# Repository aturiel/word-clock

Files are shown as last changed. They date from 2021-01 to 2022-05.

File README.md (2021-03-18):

# Spanish WordClock

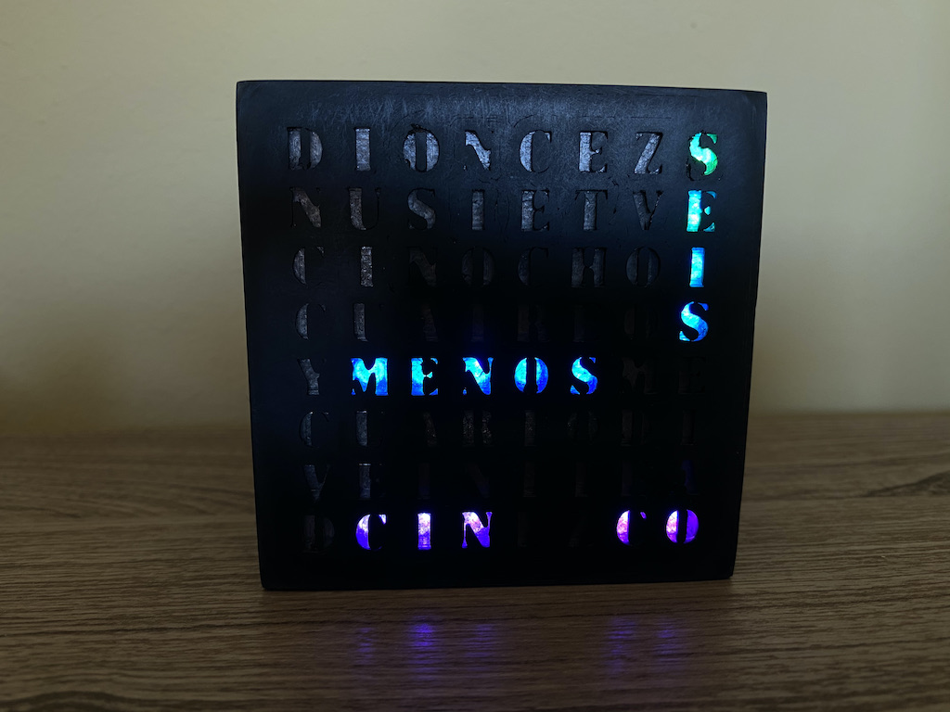
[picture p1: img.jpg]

https://www.thingiverse.com/thing:4746782

## Features include:
* Accurate Clock refresh off Internet Time Servers
* Configured through Web Interface
* Display WordClock status on web server
* Basic Authorization around Configuration web interface
* Support for OTA (loading firmware over WiFi)
* Update firmware through web interface
* Configurable leds off/off times
* Configurable rainbow animation on the hour
* Based on:
  * Marquee Scroller by Qrome - https://github.com/Qrome/marquee-scroller 
  * 3D Printable NeoMatrix 8x8 Word by PawArmy - https://www.thingiverse.com/thing:931777

## Required Parts:
* Node MCU ESP8266
* CJMCU 64 Bit WS2812 5050 RGB NeoPixel MAtrix 8x8: https://www.banggood.com/CJMCU-64-Bit-WS2812-5050-RGB-LED-Driver-Development-Board-p-981678.html
* AC-DC 5V

Note: Using the links provided here help to support these types of projects. Thank you for the support.  

## Wiring 
* Please check https://github.com/Aircoookie/WLED/wiki 
* BUZZER_PIN *  D5
* LED_PIN     D4

## 3D Printed Case
Modified to match my 8x8 LED matrix from a design by [PawArmy](https://www.thingiverse.com/thing:931777)

## Compiling and Loading to ESP8266
It is recommended to use Arduino IDE.  You will need to configure Arduino IDE to work with your board and USB port and installed the required USB drivers etc.  
* Plase check [Marquee Scroller by Qrome](https://github.com/Qrome/marquee-scroller) project

## Loading Supporting Library Files in Arduino
Use the Arduino guide for details on how to installing and manage libraries https://www.arduino.cc/en/Guide/Libraries  
**Packages** -- the following packages and libraries are used (download and install):  

"FS.h"
<ESP8266WiFi.h>
<ESP8266WebServer.h>
<ESP8266HTTPUpdateServer.h>
<WiFiManager.h> // --> https://github.com/tzapu/WiFiManager
<ArduinoOTA.h>
<NTPClient.h> // --> https://github.com/arduino-libraries/NTPClient
<Adafruit_NeoPixel.h> // --> https://github.com/adafruit/Adafruit_NeoPixel

## Web Interface
The WordClock uses the **WiFiManager** so when it can't find the last network it was connected to 
it will become a **AP Hotspot** -- connect to it **WORD-CLOCK-chipID.local** with your phone and you can then enter your WiFi connection information.

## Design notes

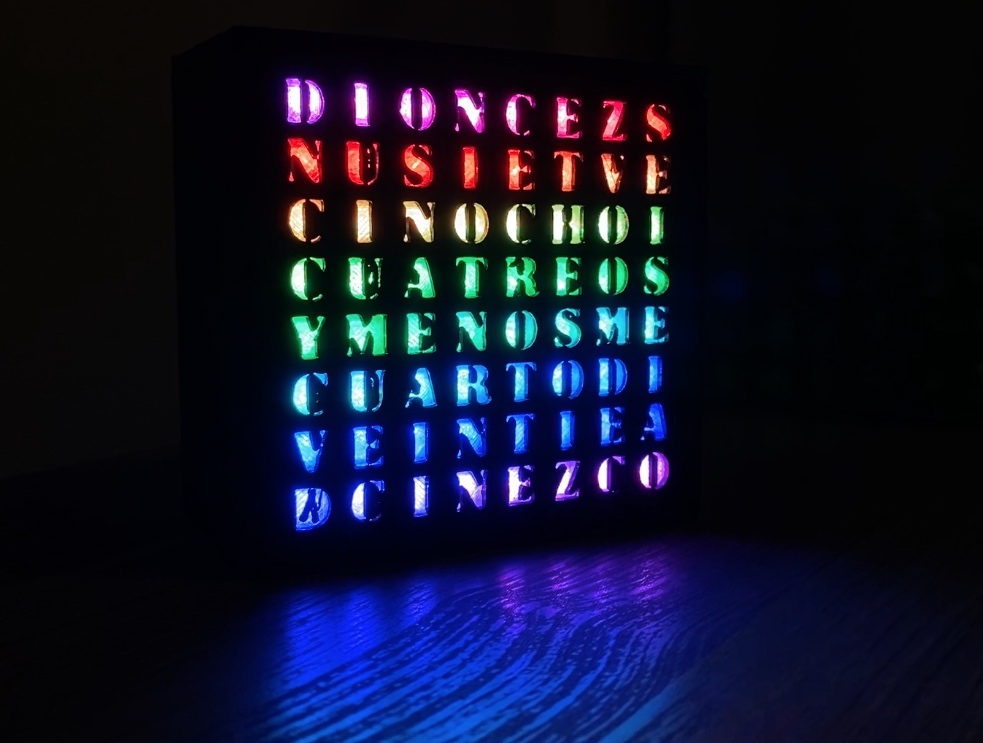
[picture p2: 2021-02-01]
STL/images/face.jpg

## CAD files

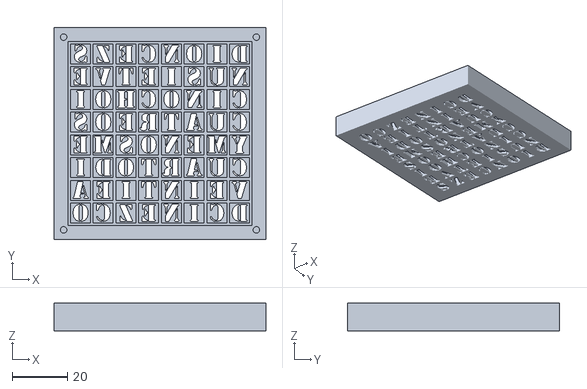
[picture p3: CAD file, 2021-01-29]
STL/3D_Printable_NeoMatrix_8x8_Word_Clock/files/Alberto - WordClock-face_spanish.stl
77.0 x 77.0 x 10.0

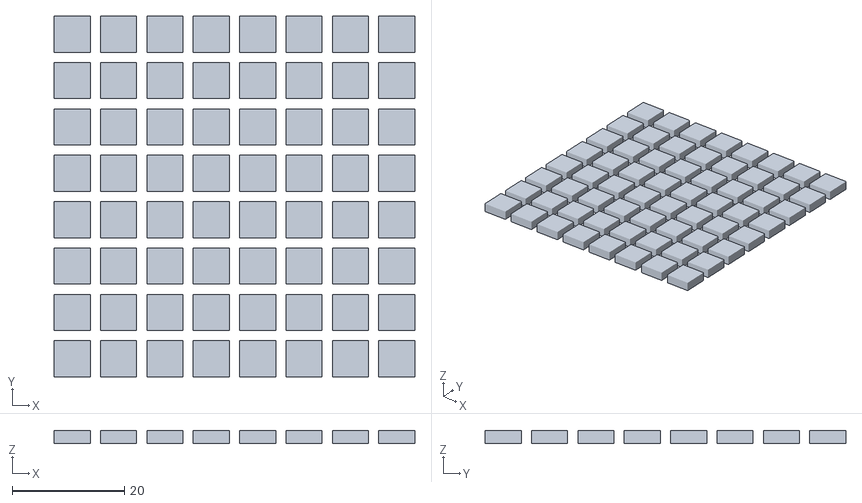
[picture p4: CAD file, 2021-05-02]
STL/WordClock-diffusers-2.stl
64.2 x 64.2 x 2.25

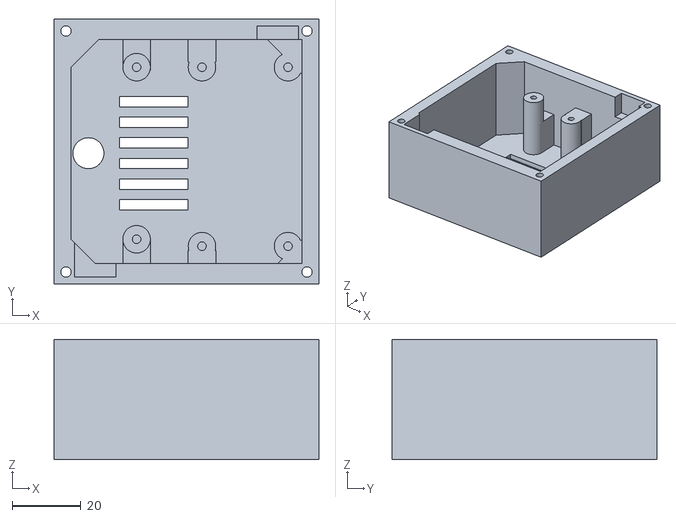
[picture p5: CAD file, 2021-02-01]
STL/WordClock-back.stl
77.0 x 77.0 x 35.0

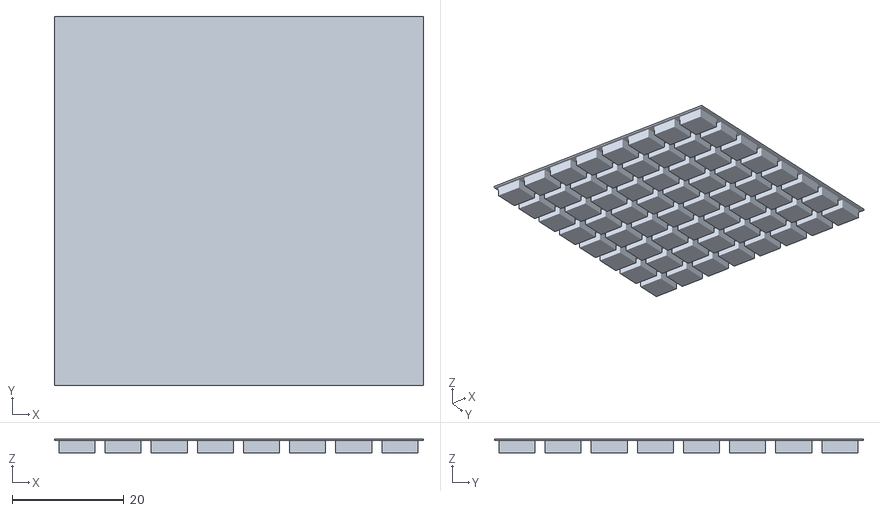
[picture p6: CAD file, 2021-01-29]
STL/WordClock-diffusers.stl
66.0 x 66.0 x 2.55

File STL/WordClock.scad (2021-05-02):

letters = [ 
    ["D", "I", "O", "N", "C", "E", "Z", "S"],
    ["N", "U", "S", "I", "E", "T", "V", "E"],
    ["C", "I", "N", "O", "C", "H", "O", "I"],
    ["C", "U", "A", "T", "R", "E", "O", "S"],
    ["Y", "M", "E", "N", "O", "S", "M", "E"],
    ["C", "U", "A", "R", "T", "O", "D", "I"],
    ["V", "E", "I", "N", "T", "I", "E", "A"],
    ["D", "C", "I", "N", "E", "Z", "C", "O"],    
];

$fn = 64;
max = 66;   // led side?
s = 66/8;
d_h = 5;    // led dividers?
w_h = 10;   // face height
b_h = 5;    // dividers height
c_h = 35;   // base height
letter_depth = w_h+1;

diffusers_height = 2.25;

font_face = "stencil std";
font_brand = "futura";

module face()
{
	for (r = [0:7])
	{
		for (c = [0:7])
		{
			#translate([r*s + s/2+.4, c*s+s/2+.5, 0])
				linear_extrude(height = letter_depth+1)
					text(
						letters[7-c][r], 
						font = font_face,
						size=6, 
						$fn=20, 
						valign="center", 
						halign = "center"
					);
		}
	}
}

module case_front()
{
	difference()
	{
		union()
		{
			translate([-5,-5,0]) 	cube([5,max+6+5, w_h]);	// left side
			translate([max+1,-5,0])	cube([5,max+6+5, w_h]); // right side 
			translate([0,max+1,0]) 	cube([max+2, 5, w_h]);	// top
			translate([-1,-5,0])	cube([max+3, 5, w_h]); 	// bottom
		}
		
		// mounting holes
		
		translate([-1.5,-1.5,0]) 			cylinder(d=2.4,h=w_h-2);	// ll 
		translate([max+1+1.5,-5+3.5,0]) 	cylinder(d=2.4,h=w_h-2);	// lr
		translate([-1.5,max+1+1.5,0]) 		cylinder(d=2.4,h=w_h-2);	// ul
		translate([max+1+1.5,max+1+1.5,0])	cylinder(d=2.4,h=w_h-2);	// ur 
	}
}

module dividers(w=1)
{
	for (x = [0:8])
	{
		translate([s*x, 1, 0]) cube([w,max,d_h]);
		translate([0, s*x,0]) cube([max+1, w, d_h]);
	}
}

module clock_face()
{
	difference()
	{
		union()
		{
			translate([0,0,w_h-1]) cube([max+1,max+1,1]);
			translate([0,0,b_h]) dividers();
		}
		face();
	}
	case_front();
}

module diffusers()
{
	difference()
	{
		translate([1,1,0]) cube([max,max,diffusers_height]);
		dividers(1.8);
	}	
    //translate([1,1,diffusers_height]) cube([max,max,0.30]);
}

module standoff( height, width_bottom, width_top)
{
	difference()
	{
		cylinder(d1=width_bottom,d2=width_top,h=height);
		translate([0,0,height-10+1])	cylinder(d=2.5, h=10);
	}
}

module case_back()
{
	difference()
	{
		union()
		{
			cube([max+1, max+1, 2]);
			translate([   -5,  -5, 0]) 		cube([5    , max+6+5, c_h]);	// left side
			translate([max+1,  -5, 0])		cube([5    , max+6+5, c_h]);    // right side 
			translate([    0, max, 0]) 	    cube([max+2,       6, c_h]);	// top
			translate([   -1,  -5, 0])		cube([max+2,       6, c_h]); 	// bottom
            
            // reinforcement bottom left
            translate([ -1, -1, 0])      
                linear_extrude(height = c_h, convexity = 10, twist = 0)
                polygon(points=[[0,0],[10,0],[0,10]], paths=[[0,1,2]]);

            // reinforcement bottom right
            #translate([ -1, max+1, 0])      
                linear_extrude(height = c_h, convexity = 10, twist = 0)
                polygon(points=[[0,0],[10,0],[0,-10]], paths=[[0,1,2]]);
            
            // reinforcement top left
            translate([ max+1, -1, 0])      
                linear_extrude(height = esp_height+2, convexity = 10, twist = 0)
                polygon(points=[[0,0],[-9,0],[0,9]], paths=[[0,1,2]]);
            
            // reinforcement top right
            translate([ max+1, max+1, 0])      
                linear_extrude(height = esp_height+2, convexity = 10, twist = 0)
                polygon(points=[[0,0],[-11,0],[0,-11]], paths=[[0,1,2]]);
		}
		
		// mount holes 
        screwDeep = 17;
		translate([     -1.5,      -1.5, 0]) 	cylinder(d=3,h=c_h+1);	// ll 
		translate([max+1+1.5,    -5+3.5, 0]) 	cylinder(d=3,h=c_h+1);	// lr
		translate([     -1.5, max+1+1.5, 0]) 	cylinder(d=3,h=c_h+1);	// ul
		translate([max+1+1.5, max+1+1.5, 0])	cylinder(d=3,h=c_h+1);	// ur 
		
		translate([     -1.5,      -1.5, 0]) 	cylinder(d=5.5,h=c_h-screwDeep);	// ll 
		translate([max+1+1.5,    -5+3.5, 0]) 	cylinder(d=5.5,h=c_h-screwDeep);	// lr
		translate([     -1.5, max+1+1.5, 0]) 	cylinder(d=5.5,h=c_h-screwDeep);	// ul
		translate([max+1+1.5, max+1+1.5, 0])	cylinder(d=5.5,h=c_h-screwDeep);	// ur 
        
        // ventilation grill
        tol = 0.2;
        translate([14,16.5,0])	
             difference(){
               linear_extrude(height = 10)
               cube([16,30,10]);
               for (y=[0:6:30]){
                   translate([0,y,0]){
                     cube([20,3,5]);
                   }
               }
             }
        
        // slots for LED connector
        led_connector_deep = 9;
		#translate([max-12, max-0.5, c_h-led_connector_deep])	cube([12, 4.5, led_connector_deep]); 	
		#translate([     1,      -3, c_h-led_connector_deep])	cube([12, 10, led_connector_deep]);
            
		// power socket cutout
		translate([5,(max/2),0])
			 cylinder(d=9,h=6, center=true);
		
        // brand
        /*
		translate([max/2+15,max/2,0.3]) rotate([180,0,90])
					linear_extrude(height = 0.3)
					text(
						"Word-Clock", 
						font = font_brand,
						size=6, 
						$fn=20, 
						valign="center", 
						halign = "center"
					);
        */
	}
    
    // debug modules
    //#translate([6, 13, 3])	cube([28, 40, 23]); 	// AC-DC
    //#translate([35, 3, 5])	cube([31, 60, 18]); 	// ESP
    
    // strandoffs
    width_bottom = 8;
    width_top = 8;
    
	// standoffs for AC-DC
    acdc_height = 24;
    acdc_length = 50;
    acdc_x = 5+5+9;
    acdc_y = 8;
	translate([acdc_x, acdc_y             , 2]) standoff(acdc_height, width_bottom, width_top);
	translate([acdc_x, acdc_y+acdc_length , 2]) standoff(acdc_height, width_bottom, width_top);
    
	// standoffs for ESP 
    esp_height = 21;
    esp_width = 25;
    esp_length = 52;
    esp_x = 5+5+28;
    esp_y = 6;
	translate([esp_x          , esp_y             , 2]) standoff(esp_height, width_bottom, width_top);
	translate([esp_x+esp_width, esp_y             , 2]) standoff(esp_height, width_bottom, width_top);
	translate([esp_x          , esp_y+esp_length  , 2]) standoff(esp_height, width_bottom, width_top);
	translate([esp_x+esp_width, esp_y+esp_length  , 2]) standoff(esp_height, width_bottom, width_top);
    
    // aditional supports for AC-DC
	#translate([acdc_x-(width_top/2), 0    , 2])    cube([8,8,14]);
	#translate([acdc_x-(width_top/2), max-9, 2]) 	cube([8,9,14]);

    // aditional supports for ESP 
	#translate([esp_x-(width_top/2),     0, 2])     cube([8,4.7,esp_height]);
	#translate([esp_x-(width_top/2), max-6.5, 2])   cube([8,7,esp_height]); 
}

// uncomment for clock face
//translate([-15,0,10]) rotate([0,180,0]) clock_face();

// uncomment for led diffusers
translate([0,-80,0]) diffusers();

// uncomment for back of case
//case_back();

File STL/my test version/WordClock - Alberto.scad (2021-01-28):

letters = [
    ["C", "U", "A", "T", "R", "E", "O", "S"],
    ["N", "U", "S", "I", "E", "T", "V", "E"],
    ["C", "I", "N", "O", "C", "H", "O", "I"],
    ["D", "I", "O", "N", "C", "E", "Z", "S"],
    ["Y", "M", "E", "N", "O", "S", "M", "E"],
    ["C", "U", "A", "R", "T", "O", "D", "I"],
    ["V", "E", "I", "N", "T", "I", "E", "A"],
    ["D", "C", "I", "N", "E", "Z", "C", "O"],
];
cells = 8;

$fn=100;

font_name = "stencil std";
font_size = 6.5;

panel_extrude = 2;
letters_extrude = 1;

led_space = 3.26;
led_side = 5;

// grid
show_grid = true;
grid_width = 1.3;
grid_height = 5;

letter_size = led_space + led_side;
total_side = letter_size * cells;
init_column = (letter_size/2);
init_row = total_side - (letter_size/2);

difference() {
    cube (size=[total_side, total_side, panel_extrude]);

    x = 0;
    y = 0; 
    for( row = [0:cells-1]) {
        for( column = [0:cells-1]) {
            translate([0,0,panel_extrude-letters_extrude])
            linear_extrude(height=letters_extrude+1)
                translate([
                    init_column + (column*letter_size), 
                    init_row - (row*letter_size)
                ])
                text(letters[row][column],
                    font=font_name, size=font_size, 
                    halign="center", valign="center");
            
            x = x + led_side + led_space;
        }
        y = y + led_side + led_space;
    }
}


if(show_grid) {
    
    for (i = [0:cells]) {
        color("red", alpha=0.5)
        translate ([0, i*letter_size, grid_height])
        cube (size=[total_side, led_space, grid_width]);
        
        color("red", alpha=0.5)
        translate ([i*letter_size, 0, grid_height])
        cube (size=[led_space, total_side, grid_width]);
    }
}

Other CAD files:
STL/WordClock-face_spanish.stl

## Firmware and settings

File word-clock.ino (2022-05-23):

/** The MIT License (MIT)

  Copyright (c) 2018 David Payne

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
  THE SOFTWARE IS PROVIDED "AS IS", WITHOUT WARRANTY OF ANY KIND, EXPRESS OR
  IMPLIED, INCLUDING BUT NOT LIMITED TO THE WARRANTIES OF MERCHANTABILITY,
  FITNESS FOR A PARTICULAR PURPOSE AND NONINFRINGEMENT. IN NO EVENT SHALL THE
  AUTHORS OR COPYRIGHT HOLDERS BE LIABLE FOR ANY CLAIM, DAMAGES OR OTHER
  LIABILITY, WHETHER IN AN ACTION OF CONTRACT, TORT OR OTHERWISE, ARISING FROM,
  OUT OF OR IN CONNECTION WITH THE SOFTWARE OR THE USE OR OTHER DEALINGS IN THE
  SOFTWARE.
*/

/**********************************************
  Edit Settings.h for personalization
***********************************************/

#include "Settings.h"
#define VERSION "1.0"

#define HOSTNAME "WORD-CLOCK-"
#define CONFIG "/conf.txt"

//declairing prototypes
void configModeCallback (WiFiManager *myWiFiManager);
int8_t getWifiQuality();

// Define NTP Client to get time
// automatic summer time => https://github.com/RoboUlbricht/arduinoslovakia/blob/master/esp8266/ntp_client/ntp_client.ino
WiFiUDP ntpUDP;
// now we have a setting in the config
//long utcOffsetInSeconds = 3600 * 2;
//NTPClient timeClient(ntpUDP, "pool.ntp.org", utcOffsetInSeconds);
NTPClient timeClient(ntpUDP, "pool.ntp.org");

// HTML to simulate word-clock
String wordClockSimulated = "";

//
int displayedMinutes = 0;
boolean displayOn = true;

ESP8266WebServer server(WEBSERVER_PORT);
ESP8266HTTPUpdateServer serverUpdater;

static const char WEB_ACTIONS1[] PROGMEM = "<a class='w3-bar-item w3-button' href='/'><i class='fas fa-home'></i> Home</a>"
    "<a class='w3-bar-item w3-button' href='/configure'><i class='fas fa-cog'></i> Configure</a>"
    "<a class='w3-bar-item w3-button' href='/display'>";

static const char WEB_ACTION2[] PROGMEM = "</a><a class='w3-bar-item w3-button' href='#' onClick='confirm(\"Are you sure your want to reboot?\") && window.location.replace(\"/reboot\");'><i class='fas fa-power-off'></i> Reboot</a>"
    "<a class='w3-bar-item w3-button' href='/systemreset' onclick='return confirm(\"Do you want to reset to default settings?\")'><i class='fas fa-undo'></i> Reset Settings</a>"
    "<a class='w3-bar-item w3-button' href='/forgetwifi' onclick='return confirm(\"Do you want to forget to WiFi connection?\")'><i class='fas fa-wifi'></i> Forget WiFi</a>"
    "<a class='w3-bar-item w3-button' href='/update'><i class='fas fa-wrench'></i> Firmware Update</a>";
//                     "<a class='w3-bar-item w3-button' href='https://github.com/Qrome/marquee-scroller' target='_blank'><i class='fas fa-question-circle'></i> About</a>";
//                     "<a class='w3-bar-item w3-button' href='/reboot'><i class='fas fa-power-off'></i> Reboot</a>"

static const char CHANGE_FORM[] PROGMEM = "<form class='w3-container' action='/saveconfig' method='get'><h2>Configure</h2>"
    "<hr>"
    "<h3>Security</h3>"
    "<p><input name='isBasicAuth' class='w3-check w3-margin-top' type='checkbox' %IS_BASICAUTH_CHECKED%> Use Security Credentials for Configuration Changes</p>"
    "<p><label>Word-Clock User ID (for this web interface)</label><input class='w3-input w3-border w3-margin-bottom' type='text' name='userid' value='%USERID%' maxlength='20'></p>"
    "<p><label>Word-Clock Password</label><input class='w3-input w3-border w3-margin-bottom' type='password' name='stationpassword' value='%STATIONPASSWORD%'></p>"
    "<hr>"
    "<h3>Night mode</h3>"
    "<p><label>Display OFF Time (24 Hour Format HH:MM -- Leave blank for always on. Both must be set to work)</label><input class='w3-input w3-border w3-margin-bottom' name='endTime' type='time' value='%ENDTIME%'></p>"
    "<p><label>Display ON Time (24 Hour Format HH:MM -- Leave blank for always on)</label><input class='w3-input w3-border w3-margin-bottom' name='startTime' type='time' value='%STARTTIME%'></p>"
    "<hr>"
    "<h3>Miscellaneous</h3>"
    "<p><label>UTC ofsset (in seconds)</label><input class='w3-input w3-border w3-margin-bottom' name='utcOffset' value='%UTC_OFFSET%'></p>"
    "<p><input name='isRainbowHour' class='w3-check w3-margin-top' type='checkbox' %IS_RAINBOW_HOUR_CHECKED%> Display rainbow animation on the hour</p>"    
    "<p><input name='isColorsPerMinute' class='w3-check w3-margin-top' type='checkbox' %IS_COLORS_PER_MINUTE%> Update colors every minute</p>"
    "<p><input name='isBuzzerEnabled' class='w3-check w3-margin-top' type='checkbox' %IS_BUZZER_ENABLED%> Buzzer active</p>"
    "<p><button class='w3-button w3-block w3-green w3-section w3-padding' type='submit'>Save</button></p></form>"
    "<script>function isNumberKey(e){var h=e.which?e.which:event.keyCode;return!(h>31&&(h<48||h>57))}</script>";

// Change the externalLight to the pin you wish to use if other than the Built-in LED
int externalLight = LED_BUILTIN; // LED_BUILTIN is is the built in LED on the Wemos

#define BUZZER_PIN  D5

// Which pin on the Arduino is connected to the NeoPixels?
#define LED_PIN    D4

// How many NeoPixels are attached to the Arduino?
#define LED_COUNT  64

// NeoPixel brightness, 0 (min) to 255 (max)
#define BRIGHTNESS 36 // Set BRIGHTNESS to about 1/7 (max = 255)

// NeoPixel library
Adafruit_NeoPixel leds = Adafruit_NeoPixel(LED_COUNT, LED_PIN, NEO_GRB + NEO_KHZ800);

const int TOTAL_ROWS = 8;
const int TOTAL_COLS = 8;

char text[TOTAL_ROWS][TOTAL_COLS] = {
  {'D', 'I', 'O', 'N', 'C', 'E', 'Z', 'S'},
  {'N', 'U', 'S', 'I', 'E', 'T', 'V', 'E'},
  {'C', 'I', 'N', 'O', 'C', 'H', 'O', 'I'},
  {'C', 'U', 'A', 'T', 'R', 'E', 'O', 'S'},
  {'Y', 'M', 'E', 'N', 'O', 'S', 'M', 'E'},
  {'C', 'U', 'A', 'R', 'T', 'O', 'D', 'I'},
  {'V', 'E', 'I', 'N', 'T', 'I', 'E', 'A'},
  {'D', 'C', 'I', 'N', 'E', 'Z', 'C', 'O'},
};
int display[TOTAL_ROWS][TOTAL_COLS] = {0};

int8_t nowHour;
int8_t nowMinute;
int8_t minuteRounded;
int8_t hourCompensated;

int8_t lastRainbowHour;

//
void setup() {
  Serial.begin (115200);
  SPIFFS.begin();

  // Initialize digital pin for LED
  pinMode(externalLight, OUTPUT);
  digitalWrite (externalLight, HIGH); // Switch off LED

  // Init leds to turn off
  leds.begin(); // INITIALIZE NeoPixel strip object (REQUIRED)
  leds.show(); // Turn OFF all pixels ASAP
  leds.setBrightness(BRIGHTNESS);

  ledsIntro();
  leds.clear(); //   Set all pixels in RAM to 0 (off)
  int ledRndPos = random(0, leds.numPixels());
  leds.setPixelColor(ledRndPos++, leds.Color(0, 255, 0));
  leds.show();

  //New Line to clear from start garbage
  Serial.println();

  loadConfig();
  leds.setPixelColor(ledRndPos++, leds.Color(0, 255, 0));
  leds.show();

  // start-up chime
  if( isBuzzerEnabled) {  
    startupChime();
  }

  //WiFiManager
  //Local intialization. Once its business is done, there is no need to keep it around
  WiFiManager wifiManager;

  // Uncomment for testing wifi manager
  //wifiManager.resetSettings();
  wifiManager.setAPCallback(configModeCallback);

  //Custom Station (client) Static IP Configuration - Set custom IP for your Network (IP, Gateway, Subnet mask)
  //wifiManager.setSTAStaticIPConfig(IPAddress(192,168,0,99), IPAddress(192,168,0,1), IPAddress(255,255,255,0));

  String hostname(HOSTNAME);
  hostname += String(ESP.getChipId(), HEX);
  if (!wifiManager.autoConnect((const char *)hostname.c_str())) {// new addition
    leds.setPixelColor(ledRndPos++, leds.Color(255, 0, 0));
    delay(3000);
    WiFi.disconnect(true);
    ESP.reset();
    delay(5000);
  } else {
    leds.setPixelColor(ledRndPos++, leds.Color(0, 255, 0));
    leds.show();
    timeClient.begin();
  }

  // print the received signal strength:
  Serial.print("Signal Strength (RSSI): ");
  Serial.print(getWifiQuality());
  Serial.println("%");

  if (ENABLE_OTA) {
    leds.setPixelColor(ledRndPos++, leds.Color(0, 255, 0));
    leds.show();
    
    ArduinoOTA.onStart([]() {
      Serial.println("Start");
    });
    ArduinoOTA.onEnd([]() {
      Serial.println("\nEnd");
    });
    ArduinoOTA.onProgress([](unsigned int progress, unsigned int total) {
      Serial.printf("Progress: %u%%\r", (progress / (total / 100)));
    });
    ArduinoOTA.onError([](ota_error_t error) {
      Serial.printf("Error[%u]: ", error);
      if (error == OTA_AUTH_ERROR) Serial.println("Auth Failed");
      else if (error == OTA_BEGIN_ERROR) Serial.println("Begin Failed");
      else if (error == OTA_CONNECT_ERROR) Serial.println("Connect Failed");
      else if (error == OTA_RECEIVE_ERROR) Serial.println("Receive Failed");
      else if (error == OTA_END_ERROR) Serial.println("End Failed");
    });
    ArduinoOTA.setHostname((const char *)hostname.c_str());
    if (OTA_Password != "") {
      ArduinoOTA.setPassword(((const char *)OTA_Password.c_str()));
    }
    ArduinoOTA.begin();
  }

  if (WEBSERVER_ENABLED) {
    leds.setPixelColor(ledRndPos++, leds.Color(0, 255, 0));
    leds.show();
    
    server.on("/", handleHome);
    server.on("/systemreset", handleSystemReset);
    server.on("/forgetwifi", handleForgetWifi);
    server.on("/configure", handleConfigure);
    server.on("/saveconfig", processConfig);
    server.on("/display", handleDisplay);
    server.on("/reboot", handleReboot);
    server.onNotFound(redirectHome);
    serverUpdater.setup(&server, "/update", www_username, www_password);
    // Start the server
    server.begin();
    Serial.println("Server started");
    // Print the IP address
    String webAddress = "http://" + WiFi.localIP().toString() + ":" + String(WEBSERVER_PORT) + "/";
    Serial.println("Use this URL : " + webAddress);
    Serial.println(" v" + String(VERSION) + "  IP:" + WiFi.localIP().toString() + "  ");
  } else {
    Serial.println("Web Interface is Disabled");
  }

  flashLED(1, 500);

  leds.clear(); //   Set all pixels in RAM to 0 (off)
  leds.show();  // Turn OFF all pixels ASAP
}

//************************************************************
// Main Looop
//************************************************************
void loop() {
  timeClient.update();

  // calculate word-time
  nowHour = timeClient.getHours() % 12;
  nowMinute = timeClient.getMinutes();
  //daysOfTheWeek[timeClient.getDay()]);
  //timeClient.getSeconds());

  // round minutes to five minutes after if remainder > 2
  int roundMinutes = nowMinute % 5;
  if ( roundMinutes != 0) {
    if (roundMinutes > 2) {
      roundMinutes = 5 - roundMinutes;
    } else {
      roundMinutes *= -1;
    }
  }
  minuteRounded = nowMinute + roundMinutes;

  if (minuteRounded > 30) {
    hourCompensated = (nowHour + 1) % 12;
  } else {
    hourCompensated = nowHour;
  }

   // this will see if we need to turn it on or off for night mode
  checkDisplay();

  // handle leds
  if (!displayOn) {
    displayedMinutes = -1;
  } else {
    // check if we need a rainbow now
    if(isRainbowHour && nowMinute == 0 && lastRainbowHour != nowHour) {
      lastRainbowHour = nowHour;
      rainbowWhell(10);
      leds.clear(); //   Set all pixels in RAM to 0 (off)
      leds.show();  // Turn OFF all pixels ASAP
    }

    // update words and colors when needed
    if( isColorsPerMinute) {
      // update colors every minute
      if(displayedMinutes != nowMinute) {
        displayedMinutes = nowMinute;
        displayWordTime();
      }
    } else {
      // update colors when hour-words changes
      if( displayedMinutes != minuteRounded) {
        displayedMinutes = minuteRounded;
        displayWordTime();
      }
    }
  }

  //
  if (WEBSERVER_ENABLED) {
    server.handleClient();
  }

  //
  if (ENABLE_OTA) {
    ArduinoOTA.handle();
  }

  delay(1000);
}

void loadConfig() {
  if (SPIFFS.exists(CONFIG) == false) {
    Serial.println("Settings File does not yet exists.");
    saveConfig();
    return;
  }
  File fr = SPIFFS.open(CONFIG, "r");
  String line;
  while (fr.available()) {
    line = fr.readStringUntil('\n');
    if (line.indexOf("timeDisplayTurnsOn=") >= 0) {
      timeDisplayTurnsOn = line.substring(line.lastIndexOf("timeDisplayTurnsOn=") + 19);
      timeDisplayTurnsOn.trim();
      Serial.println("timeDisplayTurnsOn=" + timeDisplayTurnsOn);
    }
    if (line.indexOf("timeDisplayTurnsOff=") >= 0) {
      timeDisplayTurnsOff = line.substring(line.lastIndexOf("timeDisplayTurnsOff=") + 20);
      timeDisplayTurnsOff.trim();
      Serial.println("timeDisplayTurnsOff=" + timeDisplayTurnsOff);
    }
    if (line.indexOf("utcOffset=") >= 0) {
      utcOffset = line.substring(line.lastIndexOf("utcOffset=") + 10).toInt();
      Serial.println("utcOffset=" + String(utcOffset));
      timeClient.setTimeOffset(utcOffset);
    }
    if (line.indexOf("isRainbowHour=") >= 0) {
      isRainbowHour = line.substring(line.lastIndexOf("isRainbowHour=") + 14).toInt();
      Serial.println("isRainbowHour=" + String(isRainbowHour));
    }
    if (line.indexOf("isColorsPerMinute=") >= 0) {
      isColorsPerMinute = line.substring(line.lastIndexOf("isColorsPerMinute=") + 18).toInt();
      Serial.println("isColorsPerMinute=" + String(isColorsPerMinute));
    }
    if (line.indexOf("isBuzzerEnabled=") >= 0) {
      isBuzzerEnabled = line.substring(line.lastIndexOf("isBuzzerEnabled=") + 16).toInt();
      Serial.println("isBuzzerEnabled=" + String(isBuzzerEnabled));
    }
    if (line.indexOf("www_username=") >= 0) {
      String temp = line.substring(line.lastIndexOf("www_username=") + 13);
      temp.trim();
      temp.toCharArray(www_username, sizeof(temp));
      Serial.println("www_username=" + String(www_username));
    }
    if (line.indexOf("www_password=") >= 0) {
      String temp = line.substring(line.lastIndexOf("www_password=") + 13);
      temp.trim();
      temp.toCharArray(www_password, sizeof(temp));
      Serial.println("www_password=" + String(www_password));
    }
    if (line.indexOf("IS_BASIC_AUTH=") >= 0) {
      IS_BASIC_AUTH = line.substring(line.lastIndexOf("IS_BASIC_AUTH=") + 14).toInt();
      Serial.println("IS_BASIC_AUTH=" + String(IS_BASIC_AUTH));
    }
  }
  fr.close();
}

void saveConfig() {
  // Save decoded message to SPIFFS file for playback on power up.
  File f = SPIFFS.open(CONFIG, "w");
  if (!f) {
    Serial.println("File open failed!");
  } else {
    Serial.println("Saving settings now...");
    f.println("timeDisplayTurnsOn=" + timeDisplayTurnsOn);
    f.println("timeDisplayTurnsOff=" + timeDisplayTurnsOff);
    f.println("utcOffset=" + String(utcOffset));
    f.println("isRainbowHour=" + String(isRainbowHour));
    f.println("isColorsPerMinute=" + String(isColorsPerMinute));
    f.println("isBuzzerEnabled=" + String(isBuzzerEnabled));
    f.println("www_username=" + String(www_username));
    f.println("www_password=" + String(www_password));
    f.println("IS_BASIC_AUTH=" + String(IS_BASIC_AUTH));
  }
  f.close();
  loadConfig();
}

void processConfig() {
  if (!athentication()) {
    return server.requestAuthentication();
  }
  
  timeDisplayTurnsOn = decodeHtmlString(server.arg("startTime"));
  timeDisplayTurnsOff = decodeHtmlString(server.arg("endTime"));

  utcOffset = decodeHtmlString(server.arg("utcOffset")).toInt();
  
  isRainbowHour = server.hasArg("isRainbowHour");
  isColorsPerMinute = server.hasArg("isColorsPerMinute");
  isBuzzerEnabled = server.hasArg("isBuzzerEnabled");
  
  IS_BASIC_AUTH = server.hasArg("isBasicAuth");
  String temp = server.arg("userid");
  temp.toCharArray(www_username, sizeof(temp));
  temp = server.arg("stationpassword");
  temp.toCharArray(www_password, sizeof(temp));

  saveConfig();
  redirectHome();
}

boolean athentication() {
  if (IS_BASIC_AUTH) {
    return server.authenticate(www_username, www_password);
  }
  return true; // Authentication not required
}

void handleSystemReset() {
  if (!athentication()) {
    return server.requestAuthentication();
  }

  Serial.println("Reset System Configuration");

  if (SPIFFS.remove(CONFIG)) {
    redirectHome();
    ESP.restart();
  }
}

void handleForgetWifi() {
  if (!athentication()) {
    return server.requestAuthentication();
  }
  //WiFiManager
  //Local intialization. Once its business is done, there is no need to keep it around
  redirectHome();
  WiFiManager wifiManager;
  wifiManager.resetSettings();
  ESP.restart();
}

void handleHome() {
  digitalWrite(externalLight, LOW);
  String html = "";

  server.sendHeader("Cache-Control", "no-cache, no-store");
  server.sendHeader("Pragma", "no-cache");
  server.sendHeader("Expires", "-1");
  server.setContentLength(CONTENT_LENGTH_UNKNOWN);
  server.send(200, "text/html", "");
  sendHeader();

  html += "<div class='w3-container w3-center w3-theme-l1'><h2>";
  if(displayOn) {
    html += "Lights ON";
  } else {
    html += "Lights OFF";
  }
  html += " · " + timeClient.getFormattedTime();
  /*
  html += " · " + String(nowHour) + ":" + String(nowMinute);
  html += " // compensated hour: " + String(hourCompensated);
  html += " // rounded minute: " + String(minuteRounded);
  */
  html += "</h2></div>";

  if(displayOn) {
    html += "<div class='w3-row w3-center'>" + wordClockSimulated + "</div>";
  }

  server.sendContent(String(html)); // spit out what we got

  sendFooter();
  server.sendContent("");
  server.client().stop();
  digitalWrite(externalLight, HIGH);
}

void handleConfigure() {
  if (!athentication()) {
    return server.requestAuthentication();
  }
  digitalWrite(externalLight, LOW);
  String html = "";

  server.sendHeader("Cache-Control", "no-cache, no-store");
  server.sendHeader("Pragma", "no-cache");
  server.sendHeader("Expires", "-1");
  server.setContentLength(CONTENT_LENGTH_UNKNOWN);
  server.send(200, "text/html", "");

  sendHeader();

  String form = FPSTR(CHANGE_FORM);

  // Auth
  String tmpChecked = "";
  if (IS_BASIC_AUTH) {
    tmpChecked = "checked='checked'";
  }
  form.replace("%IS_BASICAUTH_CHECKED%", tmpChecked);
  form.replace("%USERID%", String(www_username));
  form.replace("%STATIONPASSWORD%", String(www_password));

  // Time Display on/off
  form.replace("%STARTTIME%", timeDisplayTurnsOn);
  form.replace("%ENDTIME%", timeDisplayTurnsOff);

  form.replace("%UTC_OFFSET%", String(utcOffset));

  tmpChecked = "";
  if (isRainbowHour) {
    tmpChecked = "checked='checked'";
  }
  form.replace("%IS_RAINBOW_HOUR_CHECKED%", tmpChecked);

  tmpChecked = "";
  if (isRainbowHour) {
    tmpChecked = "checked='checked'";
  }
  form.replace("%IS_COLORS_PER_MINUTE%", tmpChecked);

  tmpChecked = "";
  if (isBuzzerEnabled) {
    tmpChecked = "checked='checked'";
  }
  form.replace("%IS_BUZZER_ENABLED%", tmpChecked);

  //
  server.sendContent(form); // Send the second chunk of Data

  sendFooter();
  server.sendContent("");
  server.client().stop();
  digitalWrite(externalLight, HIGH);
}

void handleReboot() {
  redirectHome();
  ESP.restart();
}

void handleDisplay() {
  if (!athentication()) {
    return server.requestAuthentication();
  }
  enableDisplay(!displayOn);
  redirectHome();
}

void redirectHome() {
  // Send them back to the Root Directory
  server.sendHeader("Location", String("/"), true);
  server.sendHeader("Cache-Control", "no-cache, no-store");
  server.sendHeader("Pragma", "no-cache");
  server.sendHeader("Expires", "-1");
  server.send(302, "text/plain", "");
  server.client().stop();
  delay(1000);
}

void sendHeader() {
  String html = "<!DOCTYPE HTML>";
  html += "<html><head><title>Word-Clock</title><link rel='icon' href='data:;base64,='>";
  html += "<meta http-equiv='Content-Type' content='text/html; charset=UTF-8' />";
  html += "<meta name='viewport' content='width=device-width, initial-scale=1'>";
  html += "<link rel='stylesheet' href='https://www.w3schools.com/w3css/4/w3.css'>";
  html += "<link rel='stylesheet' href='https://www.w3schools.com/lib/w3-theme-indigo.css'>";
  html += "<link rel='stylesheet' href='https://cdnjs.cloudflare.com/ajax/libs/font-awesome/5.8.1/css/all.min.css'>";
  html += "<style>";
  html += "div.word-clock {text-align: center; font-family: 'Courier New', monospace; font-weight: 800; font-size: 200%; margin-top: 20px; }";
  html += "div.word-clock-row { line-height: 1; }";
  html += "span.letter {color: #DDD; background-color: #EEE; padding: 2px 8px;}";
  html += "span.selected {color:white; font-weight: bold; }";
  html += "</style>";
  html += "</head><body>";
  server.sendContent(html);
  html = "<nav class='w3-sidebar w3-bar-block w3-card' style='margin-top:88px' id='mySidebar'>";
  html += "<div class='w3-container w3-theme-d2'>";
  html += "<span onclick='closeSidebar()' class='w3-button w3-display-topright w3-large'><i class='fas fa-times'></i></span>";
  html += "<div class='w3-padding'>Menu</div></div>";
  server.sendContent(html);

  server.sendContent(FPSTR(WEB_ACTIONS1));
  if (displayOn) {
    server.sendContent("<i class='fas fa-eye-slash'></i> Turn Lights OFF");
  } else {
    server.sendContent("<i class='fas fa-eye'></i> Turn Lights ON");
  }
  server.sendContent(FPSTR(WEB_ACTION2));

  html = "</nav>";
  html += "<header class='w3-top w3-bar w3-theme'><button class='w3-bar-item w3-button w3-xxxlarge w3-hover-theme' onclick='openSidebar()'><i class='fas fa-bars'></i></button><h2 class='w3-bar-item'>Word-Clock</h2></header>";
  html += "<script>";
  html += "function openSidebar(){document.getElementById('mySidebar').style.display='block'}function closeSidebar(){document.getElementById('mySidebar').style.display='none'}closeSidebar();";
  html += "</script>";
  html += "<br><div class='w3-container w3-large' style='margin-top:88px'>";
  server.sendContent(html);
}

void sendFooter() {
  int8_t rssi = getWifiQuality();
  Serial.print("Signal Strength (RSSI): ");
  Serial.print(rssi);
  Serial.println("%");
  String html = "<br><br><br>";
  html += "</div>";
  html += "<footer class='w3-container w3-bottom w3-theme w3-margin-top'>";
  html += "<i class='far fa-paper-plane'></i> Version: " + String(VERSION) + " · ";
  html += "<i class='fas fa-rss'></i> Signal Strength: ";
  html += String(rssi) + "%";
  html += "</footer>";
  html += "</body></html>";
  server.sendContent(html);
}
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

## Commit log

2021-01-28 STL files
    [Alberto - WordClock-diffusers.stl, Alberto - WordClock-face_spanish.stl, WordClock - Alberto.scad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]
2021-01-28 STL updated
    [Alberto - WordClock-face_spanish.stl, WordClock-buttons.stl, WordClock-diffusers.stl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]
2021-01-28 Arduino misc updates: led animation on the hour // led color changes every 1/5 minutes // Add configs
2021-01-28 Arduino HTML CSS style updated
2021-01-29 SCAD and STL updates
    [Alberto - WordClock-diffusers.stl, Alberto - WordClock-face_spanish.stl, WordClock-diffusers.stl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]
2021-01-29 Arduino libraries cleaning
2021-01-29 STL files updated
    [WordClock-diffusers.stl, WordClock-face_spanish.stl, WordClock.scad]
2021-01-29 Buzzer ON/OFF configuration // intro music // random start animations
    [word-clock.ino]
2021-01-30 STL case back update
    [WordClock.scad]
2021-01-30 STL case back corner reinforcements
    [WordClock.scad]
2021-02-01 STL back plate: updated ventilñation grill // remove name
    [WordClock.scad]
2021-02-01 STL folder reorganization
    [WordClock - Alberto.scad, WordClock-back.stl, WordClock-diffusers.stl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]
2021-05-02 STL updates
    [WordClock-diffusers-2.stl, WordClock-face_spanish.stl, WordClock.scad]
